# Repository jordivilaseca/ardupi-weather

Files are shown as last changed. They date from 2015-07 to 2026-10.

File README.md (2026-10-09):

# ardupi-weather
## Description
This is a weather station done using a Raspberry Pi and an Arduino. It includes a webserver to show the data that
contains the current values of the sensors, a chart with the history and a chart with the daily history (containing
minimum, maximum and the average values). The Arduino is in charge of collecting and sending the data and the
Rasbperry Pi processes and stores the data (at this moment mongo and sqlite databases are supported).

The webserver can be executed in the Raspberry Pi itself, or wherever you want. In the first case a mongo or a sqlite databases can be used, but in the second one there is only support for mongo databases.

The currently compatible sensors are the following:

 * BMP180: Barometric pressure.
 * DHTXX: Humidity and temperature.
 * BH1750: Luminance.
 * LDR: Luminance (analogical).
 * LM35: Temperature (analogical).

## Hardware tested
This package has been tested using an Arduino Nano v3 and Raspberry Pi 2. In case of using a different Raspberry Pi model there must not be differences in the connexions, but in the arduino case in most cases there will be.

## Installation

### Arduino
The following packages are used in the Arduino script, if you need some of them for your own station, they need
to be manually installed. In most cases it can be done by copying the github repositories to the libraries folder
of the pc ("~/Arduino/libraries" in linux).

 * BH1750: BH1750 - https://github.com/claws/BH1750
 * DHT22: DHT-sensor-library - https://github.com/adafruit/DHT-sensor-library
 * NRF24L01+: RF24 - https://github.com/TMRh20/RF24
 * BMP180: BMP180_Breakout - https://github.com/sparkfun/BMP180_Breakout

Once you have all the necessary packages downloaded you must be able to compile the .ino file from inside the arduino folder.

### Raspberry Pi
To install the package on a Raspberry Pi you can do the following.

```bash
sudo pip install "git+https://github.com/jordivilaseca/ardupi-weather.git#egg=ardupi-weather[rpi]&subdirectory=RaspberryPi"
```

The only difference between this and the PC installer is that in the case of the Raspberry Pi it also installs the GPIO package used in the NRF24 connexion, package not supported in a PC.

Check out the additional packages for some specific configurations.

### PC
Use the following command.

```bash
sudo pip install "git+https://github.com/jordivilaseca/ardupi-weather.git#egg=ardupi-weather&subdirectory=RaspberryPi"
```

#### Additional packages
##### NRF24L01+
[This](https://github.com/TMRh20/RF24) library has been used to add NRF24L01+ connexion between the Arduino and the Raspberry Pi. The package configuration steps are [here](http://tmrh20.github.io/RF24/RPi.html). Keep in mind that for using this hardware the SPI kernel module of the Raspberry Pi must be enabled.

## Connexions schematic
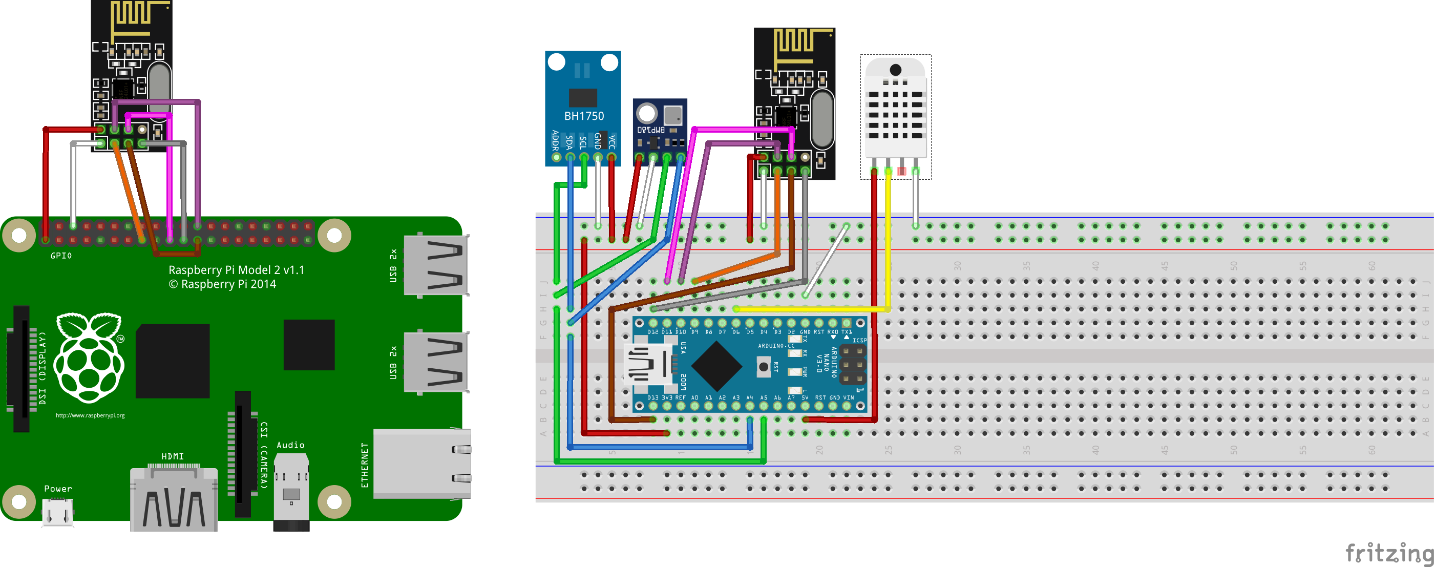
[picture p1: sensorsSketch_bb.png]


## Configuration

### Arduino
The script can be found inside the Arduino folder. To configure the arduino you must do the following.
 * Configure the connexion. Set the CONNECTION_TYPE and related variables.
 * Configure specific sensors. BMP180/DHTXX/BHT1750 have specific configuration.
 * Analogical sensor configuration (if some analogical sensor is used). Set a pin to groundPin and a pull-down circuit to it.
 * General sensor configuration. You must add a value to each one of the following variables:
  - type: Type of sensor.
  - lastUpdate: 0 as a default value.
  - updateTimes: The Arduino will send a result each updateTime milliseconds.
  - pins: The read pin for a analogical sensor, NOTUSED otherwise.

### Raspberry Pi
All the configuration of the Raspberry Pi is inside a config.yml file. This file is placed inside the folder ~/.config/ardupi_weather. The folder and the configuration file are created the first time the server or the station are launched, but you can manually create with the command `weather-station --init` or restore the default configuration with `weather-station --restore-config`.

- **arduino**: This contains all the configuration related with the Arduino.
  - **sensors**: {sensorID:valueType}. sensorID is an identifier of sensor, valueType is the type of data that the sensors sends. In case of existing more than one sensor sending the same valueType, a mean between the two sensors is computed.
  - **usedConnection**:
    - **usb**: it must be configured a port and a baud rate (the same baud rate must be configured to the Arduino)
    - **nrf24l01p**: it must be configured a repetition value, thats it the number of times the Arduino will try to send data.
    - **test**: it generates random data.

- **data**: It contains all the related information about data and databases.
  - **name**: Name of the database.
  - **values**: {valueType:dataType}. For each valueType in the Arduino sensors, you must set its dataType (FLOAT/INTEGER).
  - **usedDB**: Name of the database used (mongo/sqlite).
  - **sqlite**: Information about sqlite database (if it is not used, there is no need to configure it).
    - **path**: Path of the database. The database will be searched to path with the name described in the name field. If the path is "default" the path will be inside de configuration folder of the station.
  - **mongo**: Information about mongo database (if it is not used, there is no need to configure it).
    - **uri**: Mongo database connection uri.
  - **currentData**: Record current data into the database, the old values are updated when new ones arrive.
    - **enable**: yes/no.
    - **name**: A name for the database.
    - **updateEvery**: A dictionary. The currentData will be updated every *d* days, *h* hours, *m* minutes and *s* seconds. The value of the sensor is the last one that has arrived.
  - **history**: Record of data, it stores all the data from the first moment it was initialized. The records are made every *updateEvery* time, it calculates the average for each type of data.
    - **enable**: yes/no.
    - **name**: A name for the database.
    - **updateEvery**: A dictionary. The currentData will be updated every *d* days, *h* hours, *m* minutes and *s* seconds. The value of the sensor is the last one that has arrived.
  - **dailyHistory**: Record of daily data, it stores the daily minimum, maximum and the average for each type of data.
    - **enable**: yes/no.
    - **name**: A name for the database.

## Running

When you have the package installed you must be able to start the station using the default configuration (the data will be randomly generated).

to run the station you need write this command into the terminal `weather-station`, or for the server case `weather-server`. In case of using NRF24L01+ as a connexion, it could be you need to run the weather-station as super user `sudo weather-station`.

## Screenshots
### Webpage
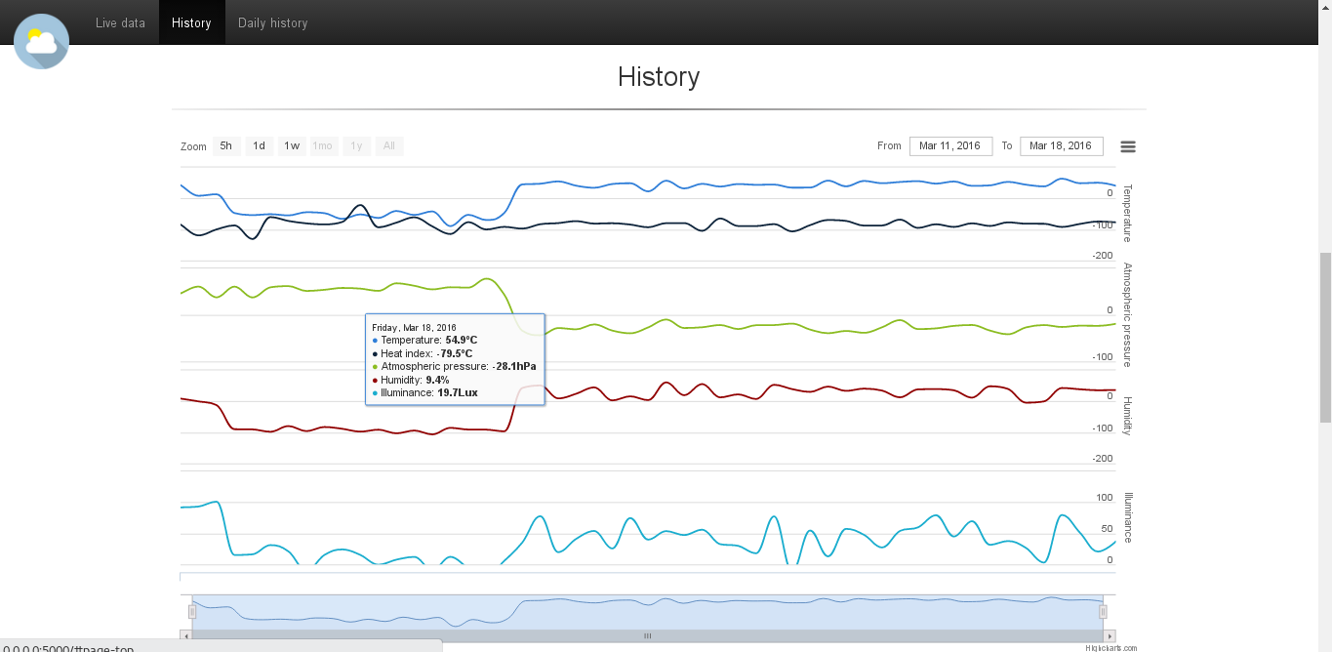
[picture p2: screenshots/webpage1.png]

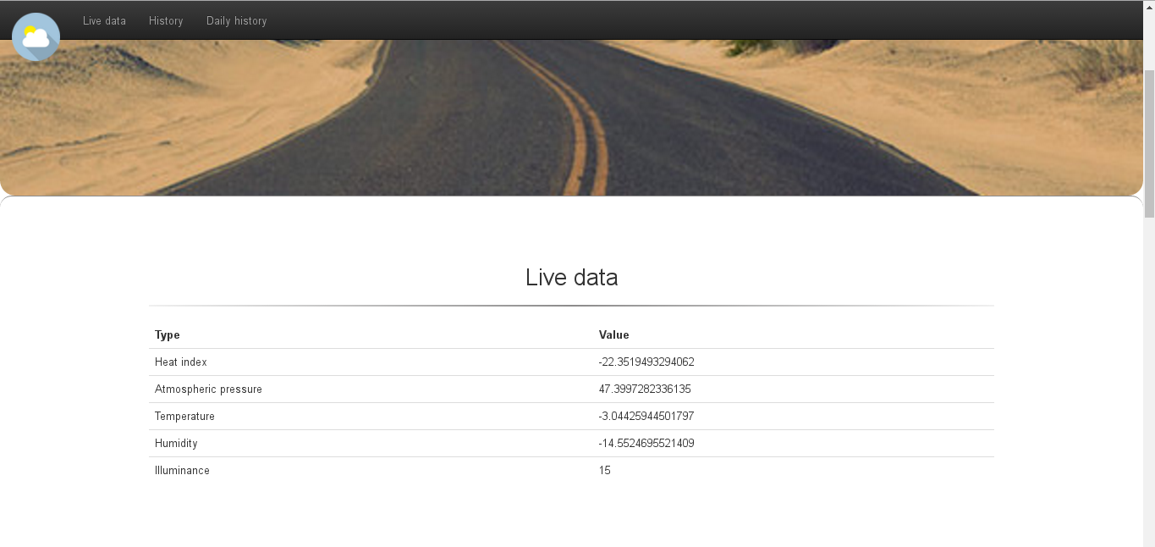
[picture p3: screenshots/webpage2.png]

### History chart
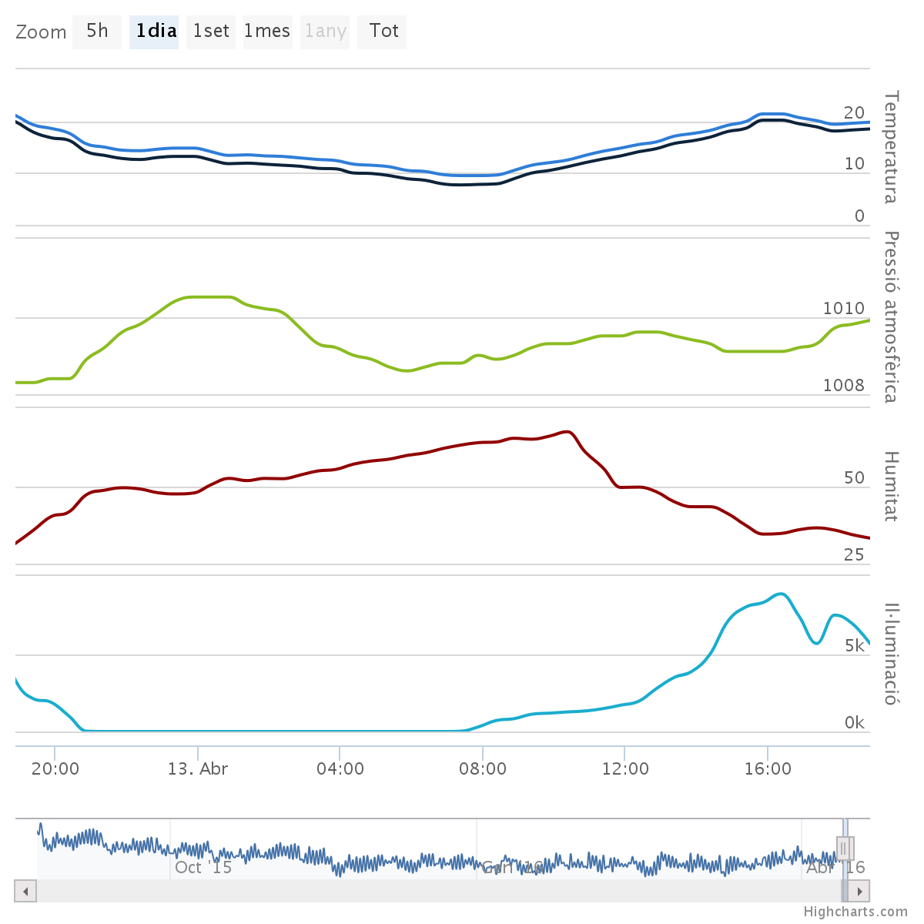
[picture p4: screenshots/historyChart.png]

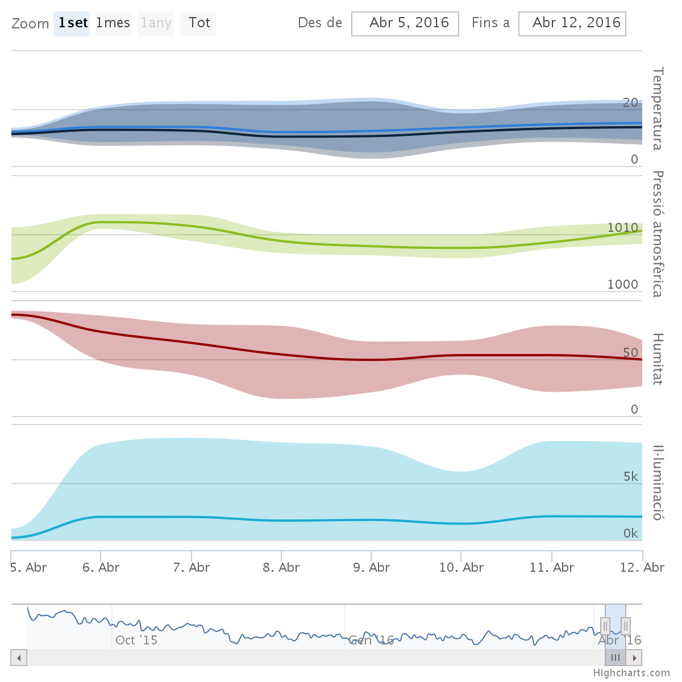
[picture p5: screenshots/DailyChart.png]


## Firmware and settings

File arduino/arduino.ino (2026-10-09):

#include <SFE_BMP180.h>
#include <BH1750.h>
#include <DHT.h>

#define count(x) sizeof(x)/sizeof(unsigned long)

#define BMP180T 0   // Temperature
#define BMP180P 1   // Pressure
#define DHT22T  2   // Temperature
#define DHT22H  3   // Humidity
#define DHT22HI 4   // Heat Index
#define BH1750L 5   // Light sensor
#define LM35    6   // Temperature (analogical)
#define LDR     7   // Light sensor (analogical)

#define NOTUSED -1  // For BMP180/DHT22/BH1750 sensor.

/*
 * CONNEXION CONFIGURATION
 */
#define CONNECTION_TYPE 2 // 0 -> USB, 1 -> 433mhz, 2 -> nrf24l01+

#if CONNECTION_TYPE == 1
  #include <VirtualWire.h>
  #define TRANSMIT_PIN 10
  #define REPETITIONS 5   // Number of times that a message will be sent. Minimum is 1
#elif CONNECTION_TYPE == 2
  #include <SPI.h>
  #include "RF24.h"
  RF24 radio(9,10);       // CE and CSN of nrf24l01+
  const uint64_t pipes[2] = { 0xF0F0F0F0E1LL, 0xF0F0F0F0D2LL };
#endif

/*
 * BMP180 CONFIGURATION
 */
#define BMP180_ENABLE true
#define ALTITUDE 570 // We need it for the barometric pressure calculus

/*
 * DHTXX CONFIGURATION
 */
#define DHT_ENABLE true
#define DHTTYPE DHT22
#define DHTPIN  6

/*
 * BH1750 CONFIGURATION
 */
 #define BH1750_ENABLE true

/*
 * ANALOG SENSOR CONFIGURATION
 */
#define groundPin A0  // In case of not having any analog it doesn't matter its value.

/*
 * GENERAL CONFIGURATION
 */
int types[] = {BMP180T,BMP180P,DHT22T,DHT22H,DHT22HI,BH1750L};
unsigned long lastUpdate[] = {0,0,0,0,0,0};
unsigned long updateTimes[] = {60000,60000,30000,30000,60000,60000};
int pins[] = {NOTUSED,NOTUSED,NOTUSED,NOTUSED,NOTUSED,NOTUSED};

/*
 * DECLARE VARIABLES
 */
#if BMP180_ENABLE
  SFE_BMP180 pressure;
#endif
#if DHT_ENABLE
  DHT dht(DHTPIN, DHTTYPE);
#endif
#if BH1750_ENABLE
  BH1750 light;
#endif

int secureAnalogRead(int pin) {
  delay(0.01);
  analogRead(groundPin);
  delay(0.01);
  return analogRead(pin);
}

boolean bmp180Temperature(double &T) {
  char status;
  status = pressure.startTemperature();
  if (status != 0) {
    delay(status);
    status = pressure.getTemperature(T);
    if(status != 0) return true;
  }
  return false;
}

boolean bmp180Pressure(double &P) {
  double T, absP;
  char status;
  if(bmp180Temperature(T)) {
    status = pressure.startPressure(3);
    if (status != 0) {
        delay(status);
        status = pressure.getPressure(absP,T);
        if (status != 0) {
          P = pressure.sealevel(absP,ALTITUDE);
          return true;
        }
      }
  }
  return false;
}

float lm35(int pin) {
  return (5.0 * secureAnalogRead(pin) * 100.0) / 1024;
}

int ldr(int pin) {
  return map(secureAnalogRead(pin), 0, 1023, 0, 100);
}

uint16_t BH1750Light() {
  return light.readLightLevel();
}

#if CONNECTION_TYPE == 0

void sendCommand(String c, String v) {
  Serial.println(c + "_" + v);
}

#elif CONNECTION_TYPE == 1

void sendData(String s) {
  const char* cchar = s.c_str();
  vw_send((uint8_t *)cchar, strlen(cchar));
  vw_wait_tx(); // Wait until the whole message is gone
}

void sendCommand(String c, String v) {
  for(int i = 0; i < REPETITIONS; i++) {
    sendData(c + "_" + v);
  }
}

#elif CONNECTION_TYPE == 2

void sendCommand(String c, String v) {
  String data = c + "_" + v;
  const char* datachar = data.c_str();

  radio.powerUp();
  radio.write(datachar, strlen(datachar));
  radio.powerDown();
}
#endif

void update(int type, int pin) {
  String c, v;
  switch (type) {
    case BMP180T:
      {
        double t;
        c = "BMP180T";
        if (bmp180Temperature(t)) v = String(t);
        else v = c + " Error";
        break;
      }

    case BMP180P:
      {
        double p;
        c = "BMP180P";
        if (bmp180Pressure(p)) v = String(p);
        else v = c + " Error";
        break;
      }

    case DHT22T:
      {
        float t = dht.readTemperature();    // Default temperature unit is ºC.
        c = "DHT22T";
        v = String(t);
        break;
      }

    case DHT22H:
      {
        float h = dht.readHumidity();
        c = "DHT22H";
        v = String(h);
        break;
      }
    case DHT22HI:
      {
        float h, t, hi;
        h = dht.readHumidity();
        t = dht.readTemperature(true);    // We need value in farenheit.
        hi = dht.computeHeatIndex(t,h);
        c = "DHT22HI";
        v = String(dht.convertFtoC(hi));
        break;
      }
    case BH1750L:
      {
        c = "BH1750";
        v = String(BH1750Light());
        break;
      }
    case LM35:
      {
        c = "LM35";
        v = secureAnalogRead(pin);
        break;
      }
    case LDR:
      {
        c = "LDR";
        v = secureAnalogRead(pin);
      }
  }
  sendCommand(c, v);
}

void updateAll() {
  for (int i = 0; i < count(updateTimes); i++) {
    unsigned long currentTime = millis();
    if (currentTime < lastUpdate[i]) {
      lastUpdate[i] = 0;
    }
    else if (currentTime - lastUpdate[i]  > updateTimes[i]) {
      update(types[i], pins[i]);
      lastUpdate[i] += updateTimes[i];
    }
  }
}

void setup() {

  #if CONNECTION_TYPE == 0
    Serial.begin(57600,SERIAL_8E1); // set the baud rate
  #elif CONNECTION_TYPE == 1
    vw_set_tx_pin(TRANSMIT_PIN);
    vw_setup(2000);       // Bits per sec
  #elif CONNECTION_TYPE == 2
    radio.begin();
    radio.setPALevel(RF24_PA_MAX);
    radio.setDataRate( RF24_250KBPS ) ;
    radio.enableDynamicPayloads();
    radio.setRetries(5,15);
    radio.openWritingPipe(pipes[0]);
    radio.openReadingPipe(1,pipes[1]);
    radio.stopListening();
  #endif

  #if BMP180_ENABLE
    pressure.begin();
  #endif

  #if DHT_ENABLE
    dht.begin();
  #endif

  #if BH1750_ENABLE
    light.begin();
  #endif

  for (int i = 0; i < count(updateTimes); i++) {
    update(types[i],pins[i]);
  }
}

void loop() {
  updateAll();
}

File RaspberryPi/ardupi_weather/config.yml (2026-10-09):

arduino:
    # Name of the sensors (it must correspond to one of the commands names send by the arduino) and a data
    # identifier.
    sensors :
        {
            BMP180T : "temperature",
            BMP180P : "pressure",
            DHT22T  : "temperature",
            DHT22H  : "humidity",
            DHT22HI : "heatIndex",
            BH1750  : "lux"
        }

    # If 'test' is used, the program generates random values for the sensors
    usedConnection: test

    usb:
        port : 'ttyACM0'
        baud : 57600

    433mhz:
        rxPin: 27   # GPIO pin
        bps: 2000
        enableRepetitions: yes
        # Time in seconds, if a value is the same as the previous one and the time between the two values is less
        # than maxRepetitionTime then the value will be seen as a repetition, and as a result will be discarded.
        maxRepetitionTime: 1

    nrf24l01p:
        repetitions: 15         # Maximum number of repetitions is 15

# All the information relative to the data and the database.
data:
    # Name of the database.
    name : 'weather'
    # Data identifier and its type.
    values :
        {
            temperature : "FLOAT",
            pressure    : "FLOAT",
            humidity    : "FLOAT",
            heatIndex   : "FLOAT",
            lux         : "INTEGER"
        }

    usedDB: "sqlite"

    sqlite:
        path : "default"

    mongo :
        uri: "mongodb://127.0.0.1:27017"

    # History record of the data.
    history:
        enable: yes
        name: "history"
        updateEvery : {d : 0, h : 0, m : 4, s : 0}

    # It can only be enabled if history is enabled
    dailyHistory:
        enable: yes
        name: "dailyHistory"

    currentData:
        enable: yes
        name: "currentData"
        updateEvery: {d: 0, h: 0, m: 2, s: 0}

webserver:
    enable: yes

    host: '0.0.0.0'
    port: 5000

    # Title and subtitle shown in the web.
    title: 'My weather'
    subtitle: ""
    headerImage: "header.jpg"       # Name of the image header, it must be at flaskfiles/static/img
    names:
        # Data identifier and the name shown in the web.
        sensors:
            {
                temperature : Temperature,
                pressure    : Atmospheric pressure,
                humidity    : Humidity,
                heatIndex   : Heat index,
                lux         : Illuminance
            }
        # Some words and the word to be shown.
        average: average
        range: range
        type: Type
        value: Value
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

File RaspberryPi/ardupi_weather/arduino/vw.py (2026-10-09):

#!/usr/bin/env python
"""
This module provides a 313MHz/434MHz radio interface compatible
with the Virtual Wire library used on Arduinos.

It has been tested between a Pi, TI Launchpad, and Arduino Pro Mini.
"""
# 2014-08-14
# vw.py

import time

import pigpio

MAX_MESSAGE_BYTES=77

MIN_BPS=50
MAX_BPS=10000

_HEADER=[0x2a, 0x2a, 0x2a, 0x2a, 0x2a, 0x2a, 0x38, 0x2c]

_CTL=3

_SYMBOL=[
   0x0d, 0x0e, 0x13, 0x15, 0x16, 0x19, 0x1a, 0x1c,
   0x23, 0x25, 0x26, 0x29, 0x2a, 0x2c, 0x32, 0x34]


def _sym2nibble(symbol):
   for nibble in range(16):
      if symbol == _SYMBOL[nibble]:
         return nibble
   return 0

def _crc_ccitt_update(crc, data):

   data = data ^ (crc & 0xFF);

   data = (data ^ (data << 4)) & 0xFF;

   return (
             (((data << 8) & 0xFFFF) | (crc >> 8)) ^
              ((data >> 4) & 0x00FF) ^ ((data << 3) & 0xFFFF)
          )

class tx():

   def __init__(self, pi, txgpio, bps=2000):
      """
      Instantiate a transmitter with the Pi, the transmit gpio,
      and the bits per second (bps).  The bps defaults to 2000.
      The bps is constrained to be within MIN_BPS to MAX_BPS.
      """
      self.pi = pi

      self.txbit = (1<<txgpio)

      if bps < MIN_BPS:
         bps = MIN_BPS
      elif bps > MAX_BPS:
         bps = MAX_BPS

      self.mics = int(1000000 / bps)

      self.wave_id = None

      pi.wave_add_new()

      pi.set_mode(txgpio, pigpio.OUTPUT)


   def _nibble(self, nibble):

      for i in range(6):
         if nibble & (1<<i):
            self.wf.append(pigpio.pulse(self.txbit, 0, self.mics))
         else:
            self.wf.append(pigpio.pulse(0, self.txbit, self.mics))

   def _byte(self, crc, byte):
      self._nibble(_SYMBOL[byte>>4])
      self._nibble(_SYMBOL[byte&0x0F])
      return _crc_ccitt_update(crc, byte)

   def put(self, data):
      """
      Transmit a message.  If the message is more than
      MAX_MESSAGE_BYTES in size it is discarded.  If a message
      is currently being transmitted it is aborted and replaced
      with the new message.  True is returned if message
      transmission has successfully started.  False indicates
      an error.
      """
      if len(data) > MAX_MESSAGE_BYTES:
         return False

      self.wf = []

      self.cancel()

      for i in _HEADER:
         self._nibble(i)

      crc = self._byte(0xFFFF, len(data)+_CTL)

      for i in data:

         if type(i) == type(""):
            v = ord(i)
         else:
            v = i

         crc = self._byte(crc, v)

      crc = ~crc

      self._byte(0, crc&0xFF)
      self._byte(0, crc>>8)

      self.pi.wave_add_generic(self.wf)

      self.wave_id = self.pi.wave_create()

      if self.wave_id >= 0:
         self.pi.wave_send_once(self.wave_id)
         return True
      else:
         return False


   def ready(self):
      """
      Returns True if a new message may be transmitted.
      """
      return not self.pi.wave_tx_busy()

   def cancel(self):
      """
      Cancels the wireless transmitter, aborting any message
      in progress.
      """
      if self.wave_id is not None:
         self.pi.wave_tx_stop()
         self.pi.wave_delete(self.wave_id)
         self.pi.wave_add_new()

      self.wave_id = None

class rx():

   def __init__(self, pi, rxgpio, bps=2000):
      """
      Instantiate a receiver with the Pi, the receive gpio, and
      the bits per second (bps).  The bps defaults to 2000.
      The bps is constrained to be within MIN_BPS to MAX_BPS.
      """
      self.pi = pi
      self.rxgpio = rxgpio

      self.messages = []
      self.bad_CRC = 0

      if bps < MIN_BPS:
         bps = MIN_BPS
      elif bps > MAX_BPS:
         bps = MAX_BPS

      slack = 0.20
      self.mics = int(1000000 / bps)
      slack_mics = int(slack * self.mics)
      self.min_mics = self.mics - slack_mics       # Shortest legal edge.
      self.max_mics = (self.mics + slack_mics) * 4 # Longest legal edge.

      self.timeout =  8 * self.mics / 1000 # 8 bits time in ms.
      if self.timeout < 8:
         self.timeout = 8

      self.last_tick = None
      self.good = 0
      self.bits = 0
      self.token = 0
      self.in_message = False
      self.message = [0]*(MAX_MESSAGE_BYTES+_CTL)
      self.message_len = 0
      self.byte = 0

      pi.set_mode(rxgpio, pigpio.INPUT)

      self.cb = pi.callback(rxgpio, pigpio.EITHER_EDGE, self._cb)

   def _calc_crc(self):

      crc = 0xFFFF
      for i in range(self.message_length):
         crc = _crc_ccitt_update(crc, self.message[i])
      return crc

   def _insert(self, bits, level):

      for i in range(bits):

         self.token >>= 1

         if level == 0:
            self.token |= 0x800

         if self.in_message:

            self.bits += 1

            if self.bits >= 12: # Complete token.

               byte = (
                  _sym2nibble(self.token & 0x3f) << 4 |
                  _sym2nibble(self.token >> 6))

               if self.byte == 0:
                  self.message_length = byte

                  if byte > (MAX_MESSAGE_BYTES+_CTL):
                     self.in_message = False # Abort message.
                     return

               self.message[self.byte] = byte

               self.byte += 1
               self.bits = 0

               if self.byte >= self.message_length:
                  self.in_message = False
                  self.pi.set_watchdog(self.rxgpio, 0)

                  crc = self._calc_crc()

                  if crc == 0xF0B8: # Valid CRC.
                     self.messages.append(
                        self.message[1:self.message_length-2])
                  else:
                     self.bad_CRC += 1

         else:
            if self.token == 0xB38: # Start message token.
               self.in_message = True
               self.pi.set_watchdog(self.rxgpio, self.timeout)
               self.bits = 0
               self.byte = 0

   def _cb(self, gpio, level, tick):

      if self.last_tick is not None:

         if level == pigpio.TIMEOUT:

            self.pi.set_watchdog(self.rxgpio, 0) # Switch watchdog off.

            if self.in_message:
               self._insert(4, not self.last_level)

            self.good = 0
            self.in_message = False

         else:

            edge = pigpio.tickDiff(self.last_tick, tick)

            if edge < self.min_mics:

               self.good = 0
               self.in_message = False

            elif edge > self.max_mics:

               if self.in_message:
                  self._insert(4, level)

               self.good = 0
               self.in_message = False

            else:

               self.good += 1

               if self.good > 8:

                  bitlen = (100 * edge) / self.mics

                  if   bitlen < 140:
                     bits = 1
                  elif bitlen < 240:
                     bits = 2
                  elif bitlen < 340:
                     bits = 3
                  else:
                     bits = 4
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

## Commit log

2015-02-11 Added arduino dump and modifications
2015-02-21 Database updated with all sensor avarage values
2015-05-02 Fixed sending of duplicated data
    [arduino.ino]
2015-06-27 Changed used sensors
2015-06-30 Bugfix: millis() overflow
2015-07-01 Added BH1750 sensor support
2015-07-05 Changed arduino sensors id
2015-07-05 Added dumping last sensor values to a file
2015-07-05 Arduino detects no valid values
2015-07-11 Fixed bug in arduino.py
    [arduino.py]
2015-07-14 Added bootstrap and socket.io
2015-07-17 Socket.io thread is stopped when no client is connected
2015-07-25 Adapted to Raspberry Python version
2015-08-10 Added fritzing sketch with the connections with the sensors
    [sensorsSketch.fzz]
2015-08-13 Station deals with intervals without connection to the arduino
2015-08-21 Improved webserver data update (charts and current data)
2015-08-25 Minor fixes in webserver appearance
    [config.yml]
2015-09-13 nextUpdates and currentData is updated instead of deleting all values and then insert them when starts the program
2016-01-24 Removed socket.io dependency
2016-01-30 Added random generation of sensor values for testing purposes
2016-03-02 Added an image containing the Arduino and RaspberryPi connections
2016-03-06 Removed usused includes from arduino.ino file
2016-03-06 Added RaspberryPi/{data,log} folders, but its files will not be tracked
2016-04-13 Simplify arduino script
